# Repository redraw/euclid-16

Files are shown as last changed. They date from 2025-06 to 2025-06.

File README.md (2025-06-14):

# euclid-16

This is a prototype of a sequencer made in a Raspberry Pi Pico. Particulary, an euclidean sequencer, whose steps can be added/removed uniformely in the grid by rotating the encoder.

https://user-images.githubusercontent.com/10843208/217061688-98ad8c04-bbb4-4034-a97a-8226e16e5d99.mp4

For the moment, features are:
- 4 voices
- 16 steps
- Audio output through PWM (optionally I2S)
- MIDI USB note output
- Clock input 5V trigger pulse (ie. used by Korg Volca, etc)
- 16 led using 2 shift registers 74hc595, or NeoPixel display
- Event-based system to hook into seq/UI events, see _src/main.py_
- Save up to 16 sequences

## Usage
- **Rotate encoder (no buttons held)** → Adjust **TEMPO**

- **Press a button** → Select **voice**

- **Hold a button + rotate encoder**:
  - **Btn 1** → Add/remove **HITS**
  - **Btn 2** → Add/remove **OFFSET**
  - **Btn 3** → Add/remove **STEPS**
  - **Btn 4** → Select sequence **(1–16)**
    - Also press **encoder button** while holding Btn 4 → **Save** sequence

- **Press encoder button** → **PLAY/STOP** sequence

- **Button combos**:
  - **Btn 1 + Btn 2** → **Clear** pattern
  - **Btn 2 + Btn 3** → **Random** pattern

## TODO
- [ ] Porting to Arduino C. Despite CircuitPython is great to play around, it doesn't provide hardware timer interrupts, which is critical to keep tempo consistent. Maybe worth trying plain MicroPython, but C surely is a better idea.
- [ ] Add more voices
- [ ] Sync out
- [x] MIDI sync in
- [x] Improve RC filter on audio PWM pin (currently, just a 4.7k + 1uF cap)

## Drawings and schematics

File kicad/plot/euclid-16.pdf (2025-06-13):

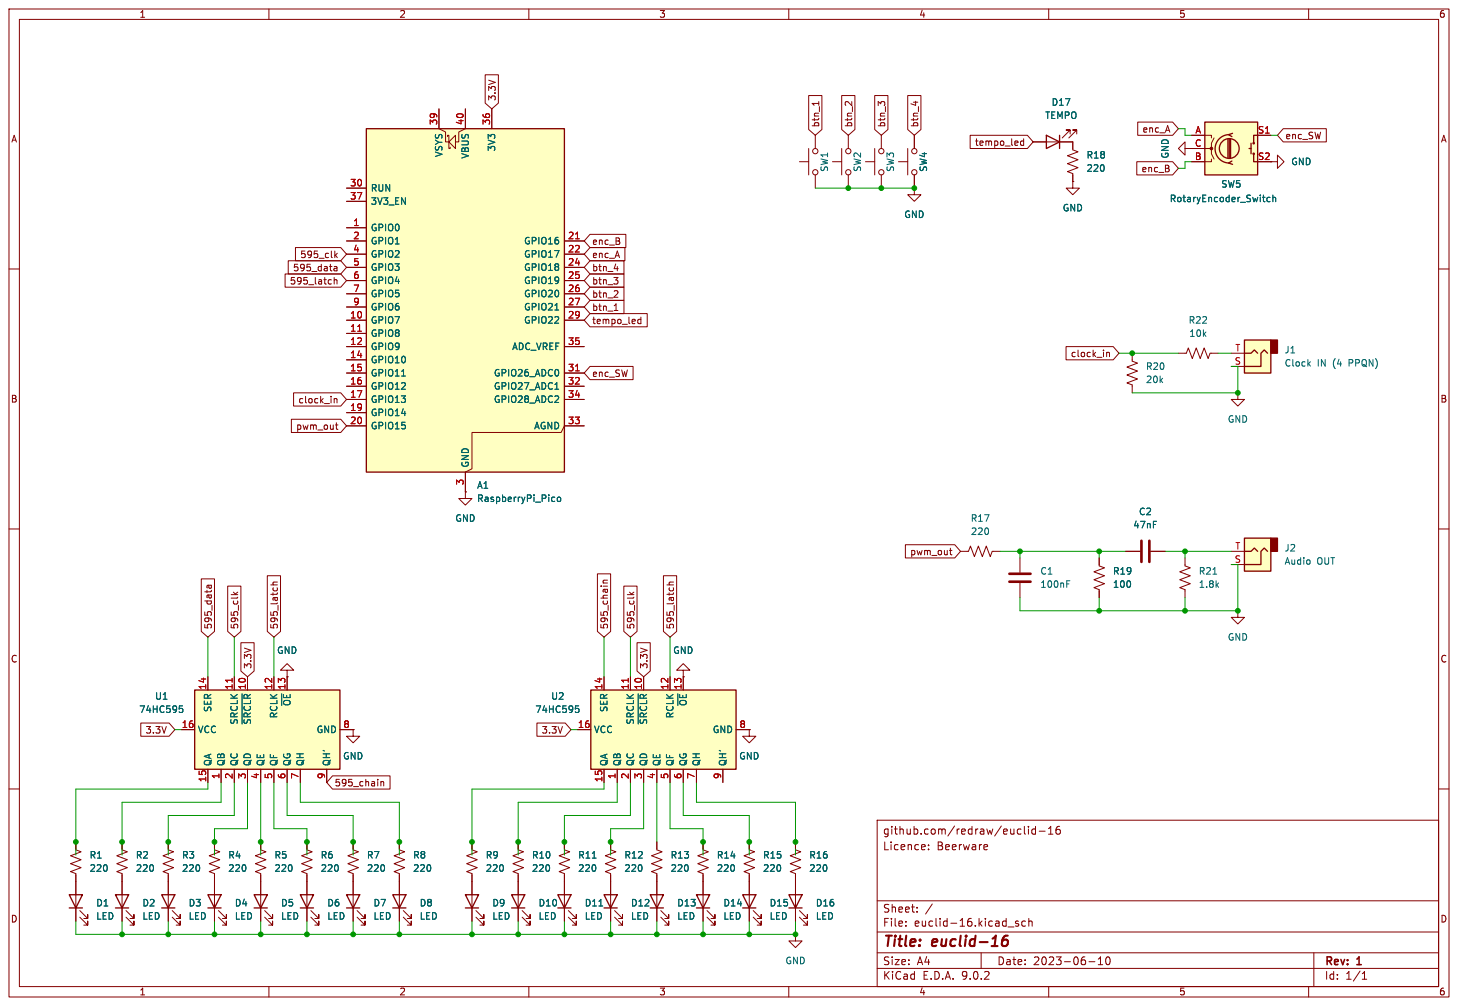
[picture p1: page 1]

7 QH' 9 GND GND GND

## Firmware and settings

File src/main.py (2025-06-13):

import os
import random
import board
import audiopwmio
# import audiobusio
import audiocore
import audiomixer

from midi import MIDI
import interface
import sequencer
import event

SAMPLE_PACK = "dr55"
SAMPLE_FOLDER = os.listdir("samplepack")
SAMPLE_RATE = 22500
MAX_VOICES = 4

dac = audiopwmio.PWMAudioOut(board.GP15)
# dac = audiobusio.I2SOut(board.GP10, board.GP11, board.GP9)
mixer = audiomixer.Mixer(voice_count=MAX_VOICES, sample_rate=SAMPLE_RATE, channel_count=1)
dac.play(mixer)

samples = []


def load_samplepack(name, randomize=False):
    global samples

    pack = f"samplepack/{name}"
    filenames = os.listdir(pack)

    for idx in range(MAX_VOICES):
        if randomize:
            filename = random.choice(filenames)
        else:
            filename = filenames[idx]
        print(f"loading {filename}...")
        samples.append(audiocore.WaveFile(open(f"{pack}/{filename}", "rb")))


def play_audio(triggers):
    for ch, trigger in enumerate(triggers):
        if trigger:
            sample = samples[ch]
            mixer.voice[ch].level = 0.8
            mixer.voice[ch].play(sample)


# Print disk info
fs_stat = os.statvfs('/')
print(f"Disk size: {fs_stat[0] * fs_stat[2] / 1024 / 1024} MB")
print(f"Free space: {fs_stat[0] * fs_stat[3] / 1024 / 1024} MB")

# Connect things!
midi = MIDI()
seq = sequencer.EuclideanSequencer(channels=MAX_VOICES, tempo=90)
seq.register(event.SEQ_STEP_TRIGGER_MIDI, midi.trigger_notes)

try:
    load_samplepack(SAMPLE_PACK, randomize=False)
    seq.register(event.SEQ_STEP_TRIGGER_CHANNELS, play_audio)
except Exception as e:
    print(e)

ui = interface.UI()
ui.register(event.UI_TEMPO_VALUE_CHANGE, seq.add_tempo)
ui.register(event.UI_HITS_VALUE_CHANGE, seq.update_hits)
ui.register(event.UI_OFFSET_VALUE_CHANGE, seq.update_offsets)
ui.register(event.UI_STEP_LENGTH_VALUE_CHANGE, seq.update_lengths)
ui.register(event.UI_PLAY_STOP, seq.toggle_play_stop)
ui.register(event.UI_PATTERN_RANDOMIZE, seq.randomize)
ui.register(event.UI_SYNC_CLOCK_IN, seq.trigger_next)
ui.register(event.UI_VOICE_CHANGE, seq.update_active_voice)
ui.register(event.UI_TRIGGER_RESET_PATTERN, seq.reset)
ui.register(event.UI_SEQUENCE_SCHEDULE, seq.schedule_sequence)
ui.register(event.UI_SEQUENCE_SAVE, seq.save_sequence)

leds = interface.LED()
ui.register(event.UI_SEQUENCE_MODE, leds.set_sequence_mode)
seq.register(event.SEQ_SEQUENCE_SELECT, leds.select_sequence)
seq.register(event.SEQ_ACTIVE_STEP, leds.toggle_tempo_led)
seq.register(event.SEQ_ACTIVE_STEP, leds.next_step)
seq.register(event.SEQ_PATTERN_CHANGE, leds.update_pattern)
seq.register(event.SEQ_SEQUENCE_SAVING, leds.set_saving_mode)
# ring = interface.NeoPixel()
# seq.register(event.SEQ_ACTIVE_STEP, ring.next_step)
# seq.register(event.SEQ_PATTERN_CHANGE, ring.update_pattern)

seq.load_sequences()
# seq.randomize()
seq.play()

while True:
    seq.update()
    ui.update()

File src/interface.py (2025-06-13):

import countio
import rotaryio
import busio
import digitalio
import board

from adafruit_debouncer import Debouncer
from adafruit_ticks import ticks_ms, ticks_diff
import neopixel
import adafruit_74hc595

import event

# pullup buttons are inverted
Debouncer.pressing = property(lambda self: not self.value)

BUTTON_PINS = (
    board.GP21,
    board.GP20,
    board.GP19,
    board.GP18,
)

ENCODER_PINS = (
    board.GP17,
    board.GP16,
)

ENCODER_BUTTON_PIN = board.GP26
TEMPO_LED_PIN = board.GP22

LEDS_595_SCLK = board.GP2
LEDS_595_DATA = board.GP3
LEDS_595_LATCH_PIN = board.GP4

SYNC_CLOCK_IN = board.GP13  # assumes PPQN = 4


class UI(event.EventEmitter):
    def __init__(self):
        super().__init__()
        self._now = ticks_ms()
        self._last_hold_millis = ticks_ms()

        self.encoder = rotaryio.IncrementalEncoder(*ENCODER_PINS)
        self._last_encoder_position = None
        self._encoder_delta = 0

        encoder_button_pin = digitalio.DigitalInOut(ENCODER_BUTTON_PIN)
        encoder_button_pin.direction = digitalio.Direction.INPUT
        encoder_button_pin.pull = digitalio.Pull.UP
        self.encoder_button = Debouncer(encoder_button_pin)

        self.buttons = []
        for pin in BUTTON_PINS:
            sw = digitalio.DigitalInOut(pin)
            sw.direction = digitalio.Direction.INPUT
            sw.pull = digitalio.Pull.UP
            button = Debouncer(sw)
            self.buttons.append(button)

        self.active_voice = 0
        self.active_menu = -1

        self.clock_in = countio.Counter(SYNC_CLOCK_IN, edge=countio.Edge.RISE)
        self._last_clock_in_count = 0
        self._clock_pulses = 0

    def update(self):
        self._now = ticks_ms()
        self.update_encoder()
        self.update_buttons()
        self.sync_clock_in()

    def update_encoder(self):
        self.encoder_button.update()
        position = self.encoder.position

        if None not in (position, self._last_encoder_position):
            self._encoder_delta = position - self._last_encoder_position
        self._last_encoder_position = position

    def update_buttons(self):
        for idx, button in enumerate(self.buttons):
            button.update()

            if button.pressing and self._encoder_delta:
                if self.active_menu != idx:
                    self.active_menu = idx

                # Hits
                if idx == 0:
                    self.emit(event.UI_HITS_VALUE_CHANGE, self.active_voice, self._encoder_delta)

                # Offset
                elif idx == 1:
                    self.emit(event.UI_OFFSET_VALUE_CHANGE, self.active_voice, self._encoder_delta)

                # Length
                elif idx == 2:
                    self.emit(event.UI_STEP_LENGTH_VALUE_CHANGE, self.active_voice, self._encoder_delta)
                
                # Load sequence
                elif idx == 3:
                    self.emit(event.UI_SEQUENCE_SCHEDULE, self._encoder_delta)

            elif button.rose and self.active_menu == idx:
                self.active_menu = -1

            # Change voice
            elif button.rose:
                self.active_voice = idx
                self.emit(event.UI_VOICE_CHANGE, self.active_voice)

        # Sequences mode
        if self.buttons[3].fell:
            self.emit(event.UI_SEQUENCE_MODE, True)

        if self.buttons[3].rose:
            self.emit(event.UI_SEQUENCE_MODE, False)

        # Save sequence
        if self.buttons[3].pressing and self.encoder_button.rose:
            self.emit(event.UI_SEQUENCE_SAVE)

        hold_millis = ticks_diff(self._now, self._last_hold_millis)

        # Reset pattern (btn 1 & 2 pressed for 1s)
        if all(self.buttons[i].pressing for i in (0, 1)) and hold_millis > 1000:
            self._last_hold_millis = self._now
            self.emit(event.UI_TRIGGER_RESET_PATTERN)

        # Random pattern (btn 2 & 3 pressed for 500ms)
        if all(self.buttons[i].pressing for i in (2, 3)) and hold_millis > 500:
            self._last_hold_millis = self._now
            self.emit(event.UI_PATTERN_RANDOMIZE)

        # Turn encoder (without buttons pressed)
        if not any(button.pressing for button in self.buttons):
            if self.encoder_button.fell:
                self.emit(event.UI_PLAY_STOP)

            if self._encoder_delta:
                self.emit(event.UI_TEMPO_VALUE_CHANGE, self._encoder_delta)

    def sync_clock_in(self):
        count = self.clock_in.count
        if count == self._last_clock_in_count:
            return

        self._clock_pulses += 1
        self._last_clock_in_count = count

        self.emit(event.UI_SYNC_CLOCK_IN, self._now)


class LED:
    def __init__(self):
        self.tempo_pin = digitalio.DigitalInOut(TEMPO_LED_PIN)
        self.tempo_pin.direction = digitalio.Direction.OUTPUT
        self.tempo_pin.value = False

        spi = busio.SPI(LEDS_595_SCLK, MOSI=LEDS_595_DATA)
        latch_pin = digitalio.DigitalInOut(LEDS_595_LATCH_PIN)
        self.sr = adafruit_74hc595.ShiftRegister74HC595(spi, latch_pin, number_of_shift_registers=2)

        self.pattern = 0b0
        self.sequence_mode = False
        self.saving_mode = False
        self.sequence_idx = 0

    def clear(self):
        self.sr.gpio = bytearray((0, 0))

    def toggle_tempo_led(self, step):
        """turn on tempo led on even numbers"""
        self.tempo_pin.value = step % 4 == 0

    def next_step(self, step):
        """sum up pattern and current step in an OR operation"""
        if self.sequence_mode or self.saving_mode: 
            return
        value = self.pattern | 1 << step
        self._update_leds(value)

    def update_pattern(self, pattern):
        self.pattern = pattern
        if self.sequence_mode or self.saving_mode:
            return
        self.show_pattern()

    def set_sequence_mode(self, enabled):
        self.sequence_mode = enabled
        if enabled:
            self.show_sequence()
        else:
            self.show_pattern()

    def set_saving_mode(self, enabled):
        self.saving_mode = enabled
        if enabled:
            self._update_leds(0xFFFF)
        else:
            self.clear()

    def select_sequence(self, idx):
        self.sequence_idx = idx
        self.show_sequence()

    def show_pattern(self):
        self.clear()
        self._update_leds(self.pattern)

    def show_sequence(self):
        self.clear()
        self._update_leds(1 << self.sequence_idx)
    
    def _update_leds(self, value):
        """value: 16 bit pattern byte"""
        # split 16-bit pattern into two 8-bit bytes (one for each shift register)
        # to display the bits as LSB-first
        self.sr.gpio = bytearray((value >> 8 & 0xFF, value & 0xFF))
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

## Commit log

2022-10-05 fix ticks_ms diff!
    The value is initialized so that the first overflow occurs about 65 seconds after power-on, making it feasible to check that your program works properly around an overflow.
    [sequencer.py]
2022-10-20 add step leds!
2022-10-20 actually update leds on pattern change
2022-10-20 add play head led
2022-10-25 turn all leds when saving
2023-08-06 add wiring diagrams
2025-06-11 add KiCad project files
    [euclid-16.kicad_pcb, euclid-16.kicad_sch]
2025-06-12 fix 3.3v ref
    [euclid-16.kicad_sch]
2025-06-13 bump circuitpython 9, fix gpio pins
    [interface.py, sequencer.py]
2025-06-13 fix clock in
    [euclid-16.kicad_sch]
2025-06-13 update sch
    [euclid-16.kicad_sch]
